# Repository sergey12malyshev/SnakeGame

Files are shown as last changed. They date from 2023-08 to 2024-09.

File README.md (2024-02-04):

# GameBox 
Game console project on STM32 controller and ILI9341 display. Contains two games: pac-man and arkanoid

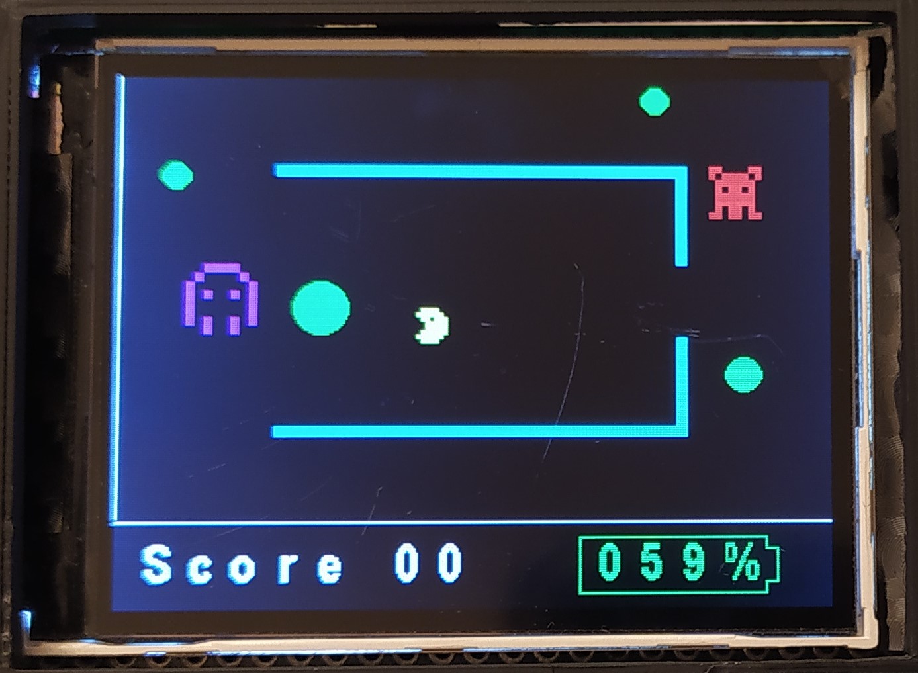
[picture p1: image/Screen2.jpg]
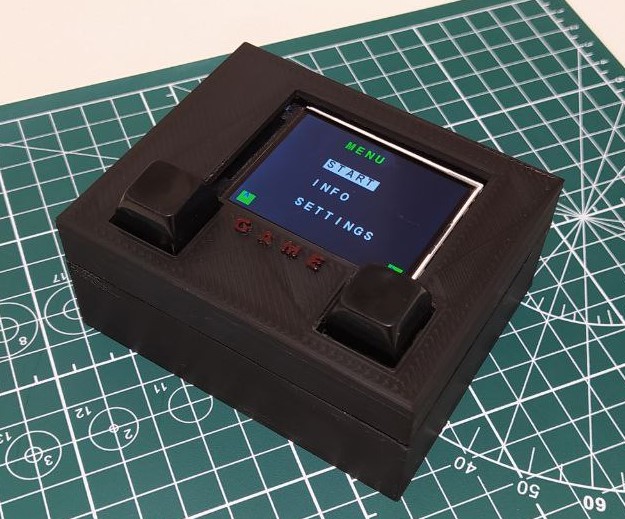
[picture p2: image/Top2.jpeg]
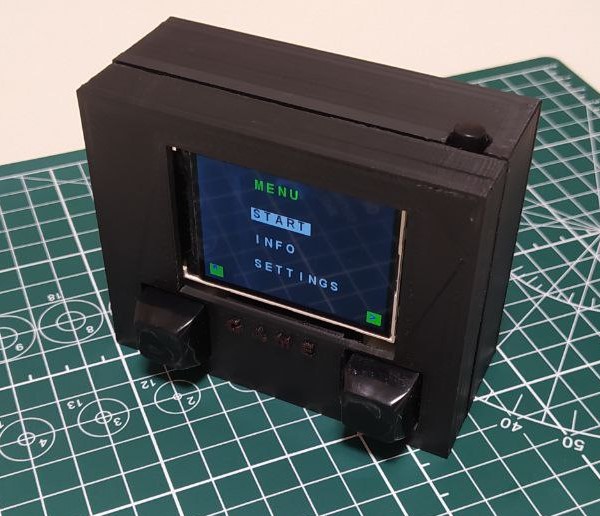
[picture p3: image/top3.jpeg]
  
 
## Tools

### Compiler
*GCC* (gcc-arm-none-eabi) version 5.4.1 20160919

### Setting up the build system in WINDOWS10 

1. Download GNU Arm Embedded Toolchain 
https://developer.arm.com/downloads/-/gnu-rm#:~:text=The%20GNU%20Arm%20Embedded%20Toolchain,Arm%20Cortex%2DR%20processor%20families
or
https://launchpad.net/gcc-arm-embedded/+download

2. Download Windows Build Tools binaries (Make, cp, rm, echo, sh...)
https://github.com/xpack-dev-tools/windows-build-tools-xpack/releases/

3. Add paths to the PATH environment variable in Windows

Подробная статья: https://habr.com/ru/articles/673522/

### RTOS
Prototreads AD v1.4

https://dunkels.com/adam/pt/

### Code editor
*VS Code* file Pac-ManGame.code-workspace

## Build 
To make the release project , run **makeProject.bat** (OR *make -j* cmd command)

To make the debug project , run **makeProjectDebug.bat** (OR *make -j1 debug* cmd command)

To clean the project, run **makeClean.bat** (OR *make clean*)

## Debugging
Open On-Chip Debugger (OCD) 0.10.0-00113-g0f83948 + GNU gdb (GNU Tools for ARM Embedded Processors) 7.10.1.20160923-cvs

Run **runOpenODC.bat** and run terminal: telnet localhost 4444

Run **runGDBserver.bat**

## Programm firmware
Connect ST-Link V2 to SWD connector. Run **programFlash.bat**

## Update firmware use system bootloader (DFU Mode)
Go to the device menu: MENU->UPDATE or CLI-> LOAD command to launch the system bootloader. Connect to PC via USB Type C. Run **updateFirmware.cmd** or launch STM32CubeProgrammer (select the desired COM-port and download the firmware).

## Command Line Interface

UART 115200 Baud rate

Connect: PA10 - RX / PA9 - TX

Terminal configuration file: utils\TERATERM.INI

Enter *help* command

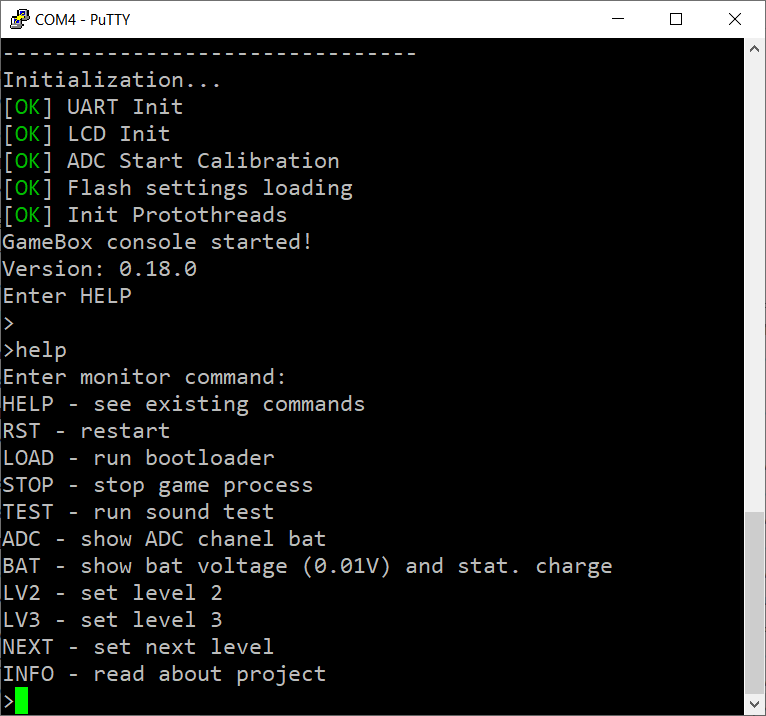
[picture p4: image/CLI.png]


### Static code analyzer
Cppcheck 2.10 https://cppcheck.sourceforge.io/

Run **RunStaticAnalysisCODE.cmd**

It is possible to output the analysis result to a file

### Unit tests
Simple unit tests are implemented in the file "unit_test.с". Unit tests are launched if the *RUN_UNIT_TEST* key is set or when building Debug

## Peripheral setup
STM32 CubeMX

(Checkboxes checked: *Enable Full Assert* и *Set All Free Pins as Analog*)

## Hardware
- Black pill STM32F103C8T6 (ARM Cortex-M3; 72 МГц; FLASH 64 кБ; ОЗУ 20 кБ)
- 2.8 TFT SPI 240x320 display (ILI9341)
- Buttons К1116КП2 (Hall effect sensor) or classic buttons
- TP4056 charge module with protection
- Battery 18650 li-ion
- CH340N USB-UART module
- Active buzzer
- Printed circuit board for soldering double-sided 7*9cm
- P-MOSFET
- USB-UART module (Optional for updating firmware via USB Type-C and working with CLI)
  
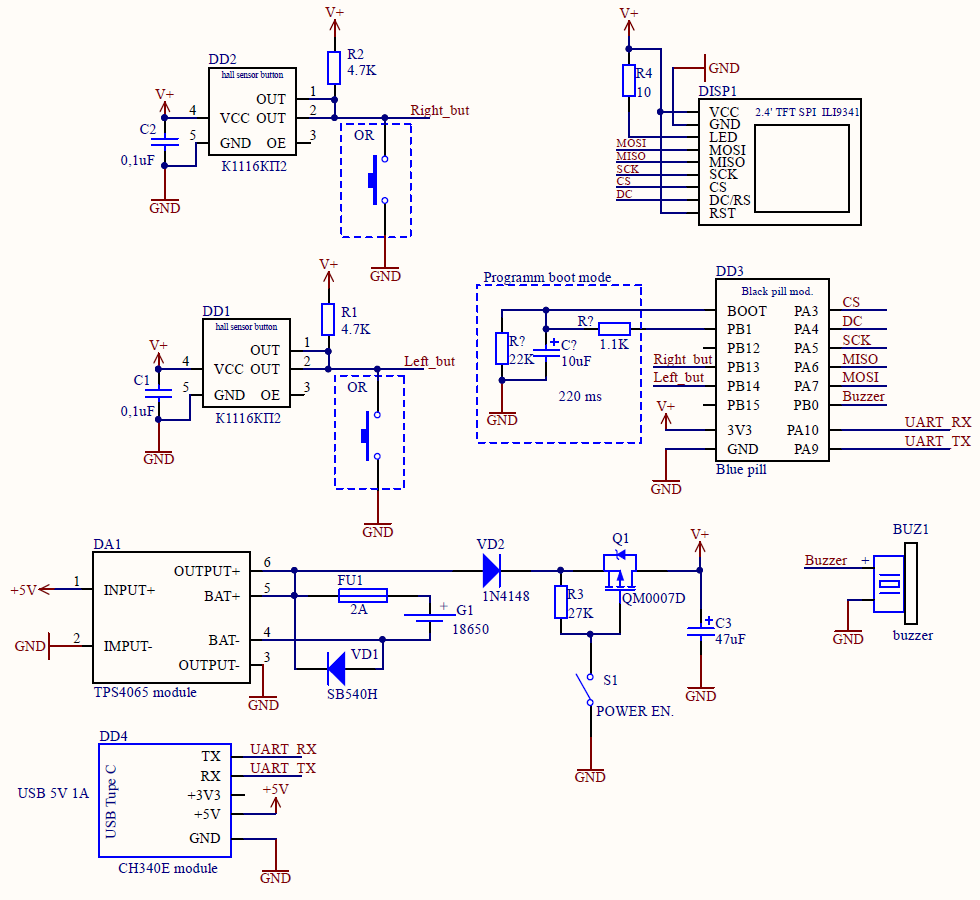
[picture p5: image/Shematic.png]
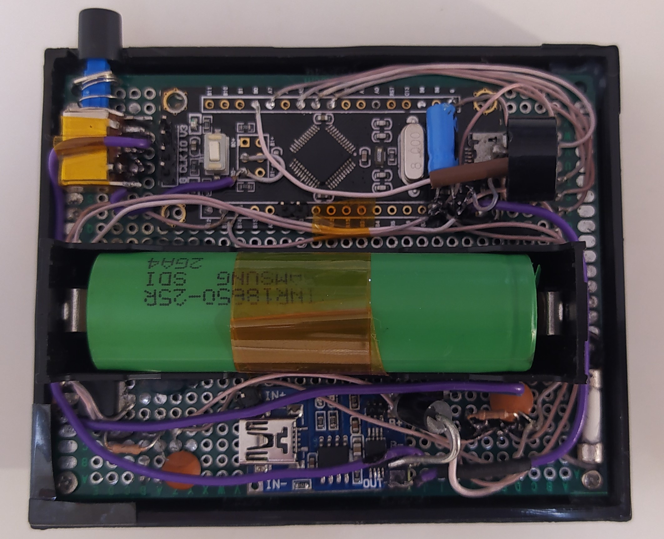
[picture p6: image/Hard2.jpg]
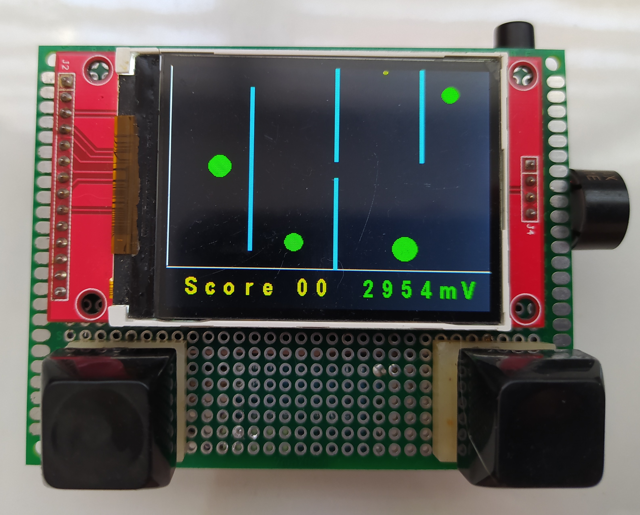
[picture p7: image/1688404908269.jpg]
   

*See Altium directory

*Be sure to check the BOOT0 output status on the debug board!*

## Case
Case models have been added to the project in the format **.stl**

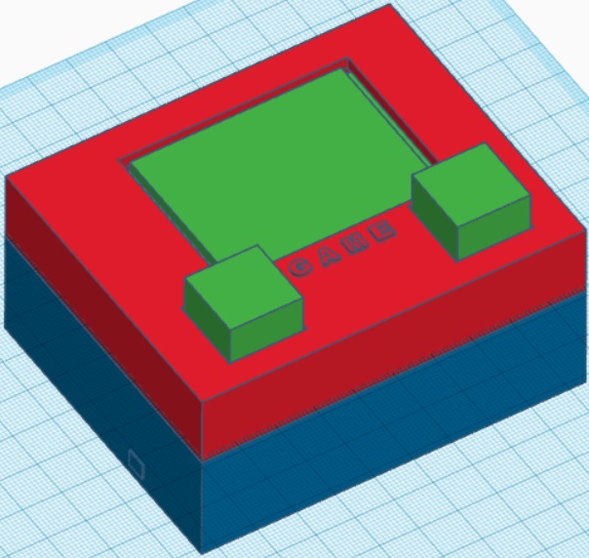
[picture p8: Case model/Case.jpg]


## gcc-arm-none-eabi

The magic name of the compiler gcc-arm-none-eabi means the following:

gcc - compiler name;

arm - processor architecture;

none - the compiler does not contribute any additional bootstrap code from itself;

eabi - code conforms to the EABI specification.

https://tuxotronic.org/post/arm-none-eabi/

## About repo

Work in the repository is carried out through the Git-flow branching model

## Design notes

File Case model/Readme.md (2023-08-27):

Корпус из двух половинок. Сделан в Tinkercad.com

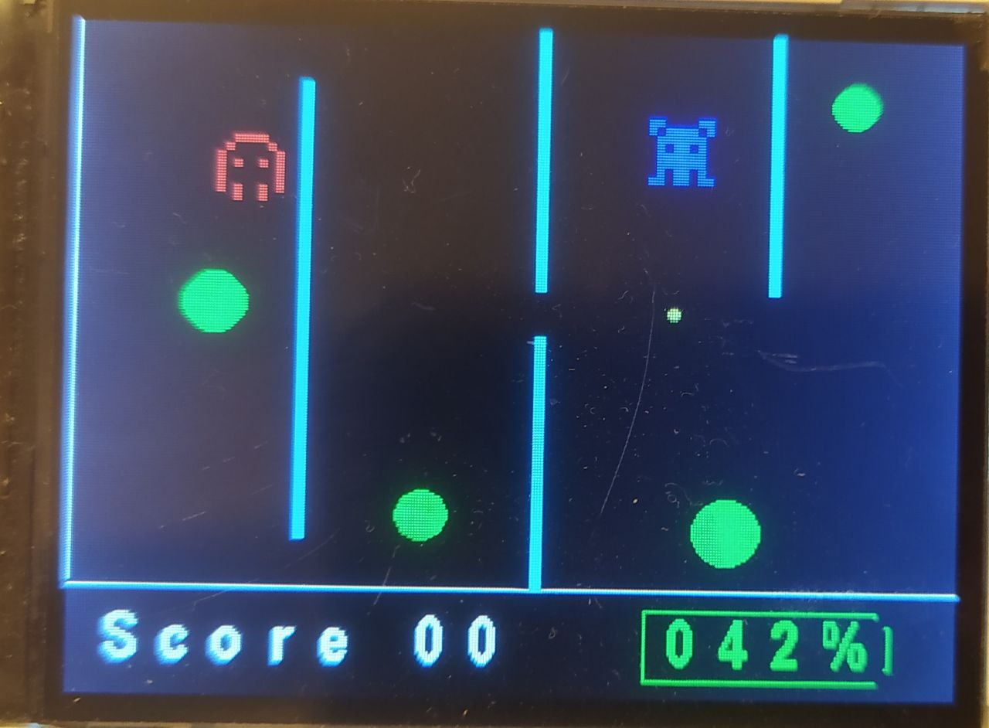
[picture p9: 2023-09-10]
image/b2e6b7b9-78c3-4203-983a-548b8aa62c95.jpg

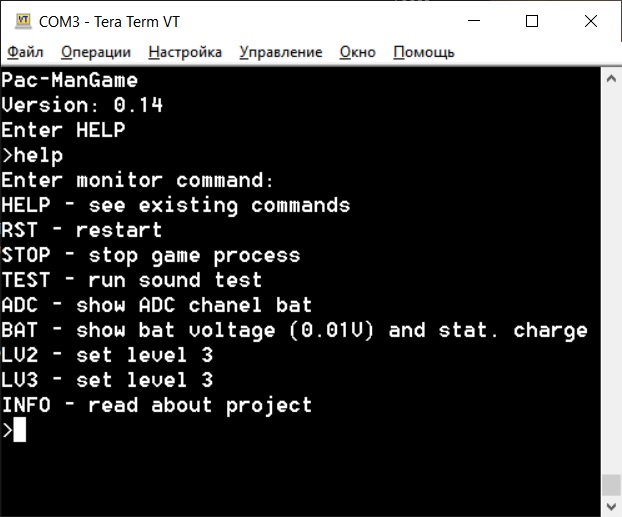
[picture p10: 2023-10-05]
image/ShellScreen.jpg

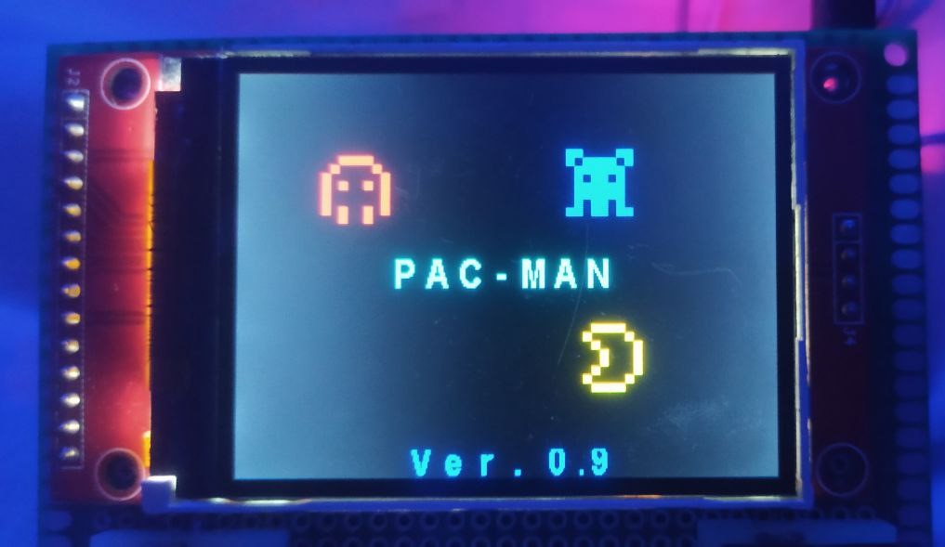
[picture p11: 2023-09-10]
image/db08b1eb-7112-4140-b000-8f4098d6f0e6.jpg

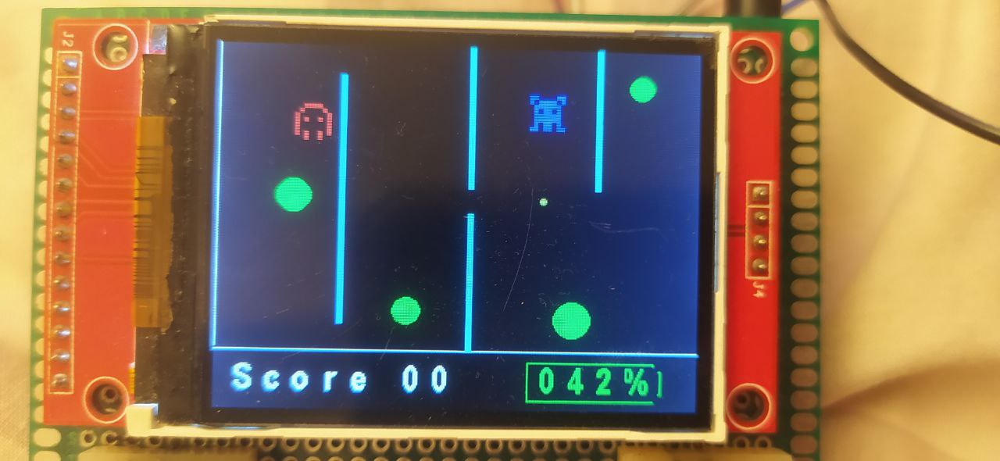
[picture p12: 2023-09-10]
image/7f3806c1-0cb3-4ed4-a501-857b09269990.jpg

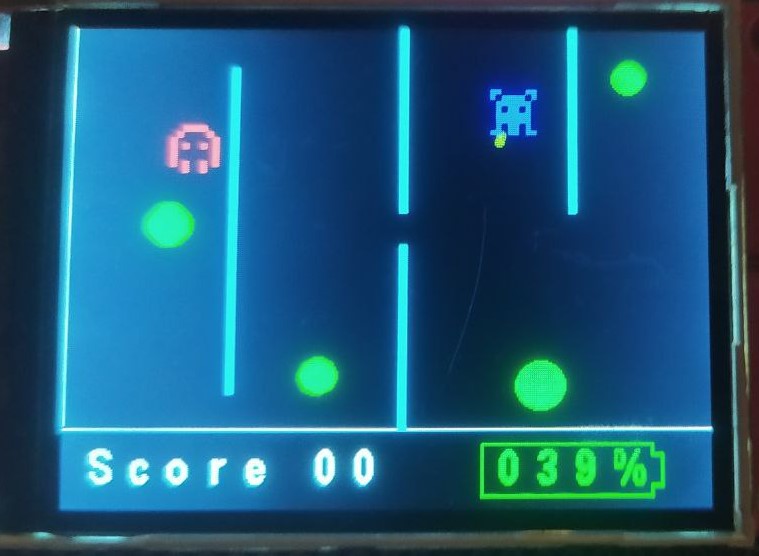
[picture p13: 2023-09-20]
image/b94825aa-9aec-4773-a235-eaeea46141b8.jpg

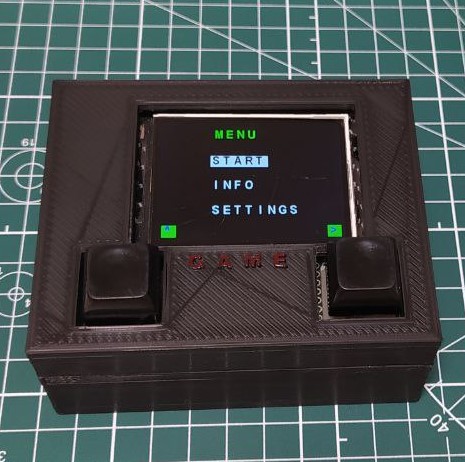
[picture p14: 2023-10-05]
image/Top.jpeg

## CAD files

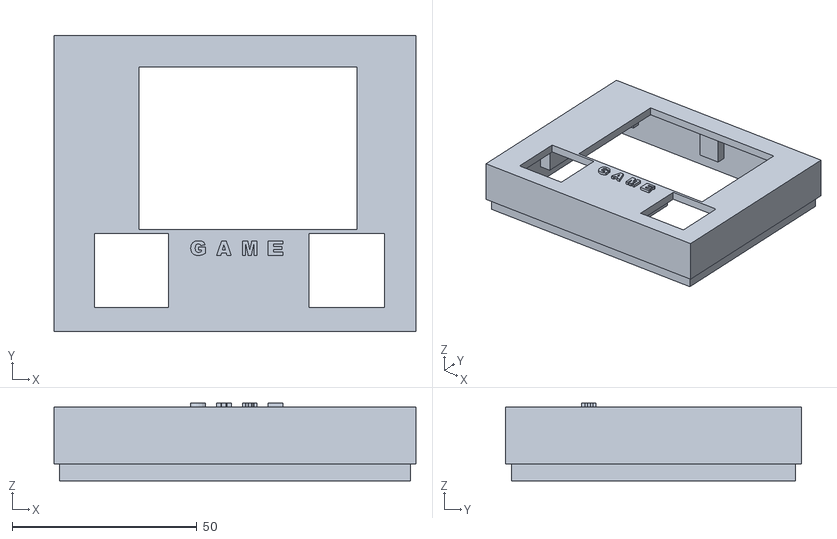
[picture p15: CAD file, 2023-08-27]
Case model/Корпус верхний.stl
98.0 x 80.0 x 21.0

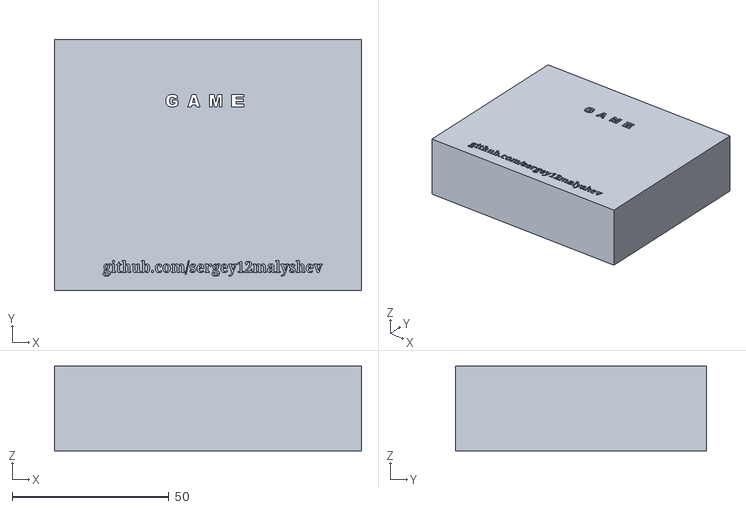
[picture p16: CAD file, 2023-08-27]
Case model/Корпус нижний.stl
98.0 x 80.0 x 27.0

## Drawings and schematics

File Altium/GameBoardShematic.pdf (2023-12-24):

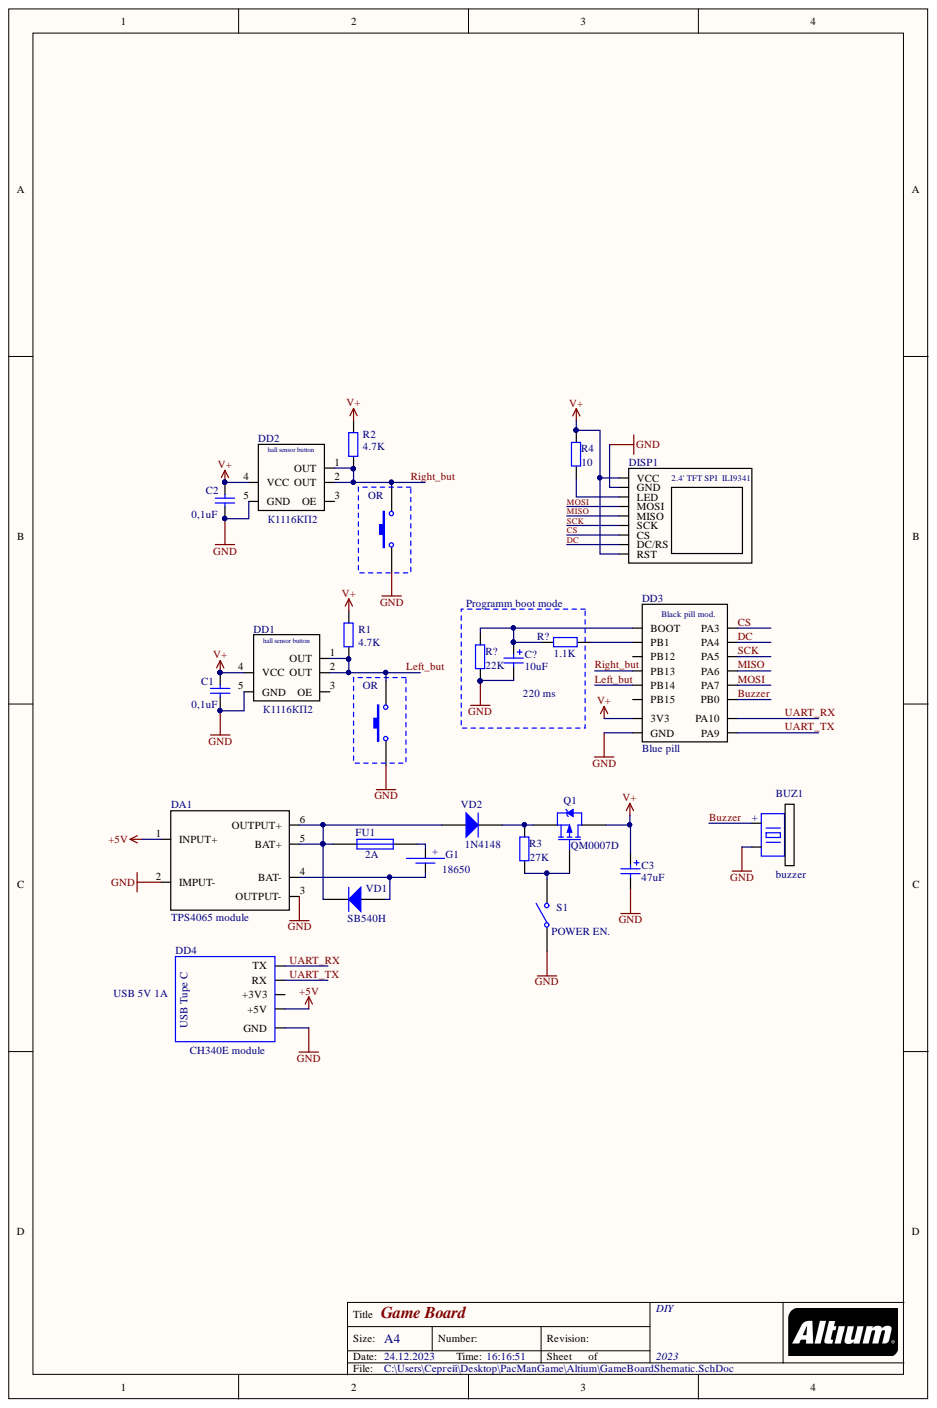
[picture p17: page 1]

Title Game Board | DIY 2023

Size: A4 | Number: | Revision:

Date: 24.12.2023 Time: 16:16:51 | | Sheet of
File: C:\Users\Сергей\Desktop\PacManGame\Altium\GameBoardShematic.SchDoc

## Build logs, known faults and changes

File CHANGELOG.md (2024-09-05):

# Version 0.20.0
Update time module
Adding GCC version check

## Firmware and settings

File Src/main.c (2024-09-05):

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
/* Includes ------------------------------------------------------------------*/
#include "main.h"

/* USER CODE BEGIN Includes */
#include <stdint.h>
#include <stdbool.h>
#include <stdio.h>
#include <string.h>
#include <stdlib.h>
#include <math.h>

#include "SPI_TFT.h"
#include "hard.h"
#include "Screens.h"
#include "Sound.h"
#include "filter.h"
#include "Menu.h"
#include "unit_test.h"
#include "workState.h"

#include "gameEngineThread.h"
#include "arkanoidEngineTread.h"
#include "batteryCheckThread.h"
#include "monitorThread.h"

#define LC_INCLUDE "lc-addrlabels.h"
#include "pt.h"
/* USER CODE END Includes */

/* USER CODE BEGIN PD */
#define GCC_VERSION ((__GNUC__ * 100) + (__GNUC_MINOR__ * 10) + ( __GNUC_PATCHLEVEL__ ))

#define STR_HELPER(x) #x
#define STR(x) STR_HELPER(x)

// Firmware builds require at least GCC 5.4.1
#if (GCC_VERSION < 541)
	#error "GCC compiler >= 5.4.1 required"
  #pragma message("GCC is " STR(__GNUC__)"."STR(__GNUC_MINOR__)"."STR(__GNUC_PATCHLEVEL__))
#endif
/* USER CODE END PD */

ADC_HandleTypeDef hadc1;

SPI_HandleTypeDef hspi1;
DMA_HandleTypeDef hdma_spi1_tx;

UART_HandleTypeDef huart1;

/* USER CODE BEGIN PV */
static struct pt gameEngine_pt;
static struct pt arkanoid_pt;
static struct pt batteryCheck_pt;
static struct pt monitorCheck_pt;

const int16_t SWversionMajor = 0;
const int16_t SWversionMinor = 20;
const int16_t SWversionPatch = 0;

const char HWversion[] = "1.0.0";

/* USER CODE END PV */

void SystemClock_Config(void);
static void MX_GPIO_Init(void);
static void MX_DMA_Init(void);
static void MX_ADC1_Init(void);
static void MX_SPI1_Init(void);
static void MX_USART1_UART_Init(void);
/* USER CODE BEGIN PFP */

/* USER CODE END PFP */

/* USER CODE BEGIN 0 */

void initProtothreads(void)
{
  PT_INIT(&gameEngine_pt);
  PT_INIT(&batteryCheck_pt);
  PT_INIT(&monitorCheck_pt);
}
/* USER CODE END 0 */

/**
  * @brief  The application entry point.
  * @retval int
  */
int main(void)
{
  /* MCU Configuration--------------------------------------------------------*/

  /* Reset of all peripherals, Initializes the Flash interface and the Systick. */
  HAL_Init();

  /* Configure the system clock */
  SystemClock_Config();

  /* Initialize all configured peripherals */
  MX_GPIO_Init();
  MX_DMA_Init();
  MX_ADC1_Init();
  MX_SPI1_Init();
  MX_USART1_UART_Init();
  /* USER CODE BEGIN 2 */
  sendUART("--------------------------------\r\n");
  sendUART("Initialization...\r\n");
  heartBeatLedEnable();
  UART_receve_IT();
  sendUART(OK_G "UART Init\r\n");
  HAL_Delay(250); // Добавим задержку, для исключения дребезга питания
  LCD_Init();
  LCD_setOrientation(ORIENTATION_LANDSCAPE_MIRROR);
  sendUART(OK_G "LCD Init\r\n");
  screenBootProcess();
  HAL_Delay(1500); 
  screenSaver();
  resetTest();
  HAL_Delay(150);
  soundPowerOn();

  HAL_ADCEx_Calibration_Start(&hadc1);
  HAL_ADC_Start_IT(&hadc1);
  sendUART(OK_G "ADC Start Calibration\r\n");
  
  #if RUN_UNIT_TEST
  runUnitTests();
  #endif

  HAL_Delay(900);
  setDefaultValueFilter(3200U);

  uint32_t speedIsFlash = flash_read(flash_get_page());
  if (speedIsFlash < 55U)
  {
    setSpeedGame(speedIsFlash);
    sendUART(OK_G "Flash settings loading\r\n");
  }
  screenMainMenu();

  initProtothreads();
  sendUART(OK_G "Init Protothreads\r\n");
  sendUART_hello();
  /* USER CODE END 2 */

  /* Infinite loop */
  /* USER CODE BEGIN WHILE */
  while (1)
  { 
    BatteryCheckThread(&batteryCheck_pt);
    MonitorTread(&monitorCheck_pt);

    switch (getWorkState())
    {
      case MENU:
        mainMenu();
        break;
      case GAME1:
        GameEngineThread(&gameEngine_pt);
        break;
      case GAME2:
        ArcanoidGameEngineThread(&arkanoid_pt);
        break;
    
      default:
        assert_param(0); // Error
        break;
    }
    /* USER CODE END WHILE */

    /* USER CODE BEGIN 3 */
  }
  /* USER CODE END 3 */
}

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


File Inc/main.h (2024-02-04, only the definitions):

#define DC_Pin GPIO_PIN_3
#define DC_GPIO_Port GPIOA
#define CS_Pin GPIO_PIN_4
#define CS_GPIO_Port GPIOA
#define BOOT_EN_Pin GPIO_PIN_1
#define BOOT_EN_GPIO_Port GPIOB
#define LED_Pin GPIO_PIN_12
#define LED_GPIO_Port GPIOB
#define WDT_CLEAR   __NOP() // заготовка под wdt
#define OK_G "[\033[32mOK\033[0m] "

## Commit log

2023-06-20 Первая фиксация demo
2023-06-20 Добавление реакции на касание еды. Добавление функционала
2023-06-21 Добавление второй кнопки
2023-06-22 Устранение проблемы с положениями
2023-06-22 Сделана реакция на касание стены
2023-06-22 Первая рабочая версия
2023-06-22 Промежуточная фиксация
2023-06-22 Фиксация
2023-06-22 Разные размеры еды
2023-06-23 Перенёс файл дисплея
2023-06-23 Отформатировал библиотеку
2023-06-23 Добавление функционала по контролю за питанием
2023-06-23 Доработка функционала
2023-06-23 Пересборка проекта с новой версией пакетов cubeMX
2023-06-24 Выделение железной логики в отдельный файл
2023-06-24 Вынесение железной логики в отдельеые файлы. Добавил версию
2023-06-25 Добавление функции звука
2023-06-25 Настройка порта под звук
2023-06-25 Поправил размеры поля
2023-06-25 Изменение распиновки
2023-06-25 Добавление функционала
2023-06-26 Увеличил размер змейки
2023-06-27 Перевод проекта на компилятор gcc систему сборки Make
2023-06-27 Уменьшение количества генерируемых CubMX-ом файлов
2023-06-27 Добавление скриптов автоматизированной сборки
2023-06-27 Дополнение README.md
2023-06-27 Добавление скрипта статического анализа кода
2023-06-27 Все свободные пины в аналоговый режим и включаем полный контроль ошибок
2023-06-28 Правка README.md
2023-06-28 Добавил даташиты
2023-06-29 Реализация уровней
2023-06-29 Реализация второго уровня
2023-06-30 Выделение логики levelUp
2023-06-30 Усложнение уровня
2023-06-30 Забыл убрать заглушку
2023-07-03 Добавление фото
2023-07-04 Выводим процент заряда
2023-07-05 Доработка алгоритма определения напряжения АКБ
2023-07-05 Добавление графика расчета SOC
    [SOC_vs_Voltage.xlsx]
2023-07-06 Добавление контура батареи. Перекодировка в UTF8
2023-07-06 Доработка символа АКБ
2023-07-06 дизигн
2023-07-06 Создание третьего уровня
2023-08-02 Добавил комментарий
2023-08-02 Обновление номера версии
2023-08-05 Увеличил предел по напряжению
2023-08-19 Множество изменений: - добавление протопотоков - разделение кода на файлы - выводим размер прошивки при сборке
2023-08-19 Реализация протопотоков
2023-08-20 Рефакторинг
2023-08-20 Устранение ошибки
2023-08-20 Выделение API работы со звуком в отдельный файл
2023-08-20 Реализация изображений
2023-08-20 Переименование игры в Pac-Men
2023-08-20 Добавление файла для ручной конвертации изображений
    [ImageDecode.xlsx]
2023-08-20 Доработка дизайна заставки
2023-08-21 Добавление монстров в игровой процесс
2023-08-21 Оптимизация
2023-08-21 Изменил расположение монстров
2023-08-22 Добавление проверки на попадание в монстров Добавил атрибут для отключения предупреждения
2023-08-23 Доработка монстров
2023-08-23 -Забыл добавить исходники звука - Переименование проекта
2023-08-25 Реализация меню
2023-08-25 Оптимизация драйвера кнопок
2023-08-26 Уменьшил кучу, увеличил стэк Переименовал файл настройки пректа
2023-08-26 Изменение дизайна и имени прошивки
2023-08-27 Проведен рефакторинг кода: выделение цветов в отдельный файл
2023-08-27 Добавление моделей корпуса
    [Корпус верхний.stl, Корпус нижний.stl]
2023-08-27 Меняем цвет монстров
2023-08-30 Добавление информации о времени сборки
2023-08-30 Добавил коммент
2023-09-06 Объявляем локально внешние переменные
2023-09-10 Добавление терминала (CLI)
2023-09-10 add jpg case
2023-09-17 Условная компиляция монитора
2023-09-18 Обновление README.md
2023-09-20 1. Add monitor command 2. Eliminating the gaming process error
    [monitorThread.c]
2023-09-20 Добавляем настройку портов
2023-09-20 Add Altium project
    [GameBoardShematic.SchDoc, Schlib1.SchLib]
2023-09-20 Переделка процесса работы с АКБ
2023-09-22 1. Cчетчик очков растёт до проигрыща 2. рефакторинг
2023-09-23 Добавил фильтр на напряжение АКБ
2023-09-23 Добавляем PDF на кнопку
2023-09-23 update model
    [ImageDecode.xlsx]
2023-09-25 устранение ошибки с неверным положением
2023-09-25 Shematic update
    [GameBoardShematic.SchDoc, Schlib1.SchLib]
2023-10-05 Add image case
2023-10-07 Add check assert failed
    [main.c]
2023-10-07 Работаем с ADC через прерывания. Увеличиваем время сэмплирования
2023-10-19 1. Добавляем предустановку фильтра 2. Подготовил макрос под WDT 3. Пищим бипером при аварии АКБ 4. Выходим по кнопке из STOP-теста
2023-11-12 Create utills directory. Add Teraterm config file
    [ImageDecode.xlsx]
2023-12-13 Add CMSIS driver Flash
2023-12-24 Добавление возможности программирования через системный загрузчик переходя из целевой программы
2023-12-24 Update Altium project
    [GameBoardShematic.SchDoc, Schlib1.SchLib]
2024-01-03 Добавление проверки при дебаге на неверные зеачения switch-case
2024-01-04 Забыл закоммитить файлы
2024-01-04 Доработка меню и графики
2024-01-04 Макрос USE_FULL_ASSER устанавливаем в debug сборке
2024-03-14 Add all drivers

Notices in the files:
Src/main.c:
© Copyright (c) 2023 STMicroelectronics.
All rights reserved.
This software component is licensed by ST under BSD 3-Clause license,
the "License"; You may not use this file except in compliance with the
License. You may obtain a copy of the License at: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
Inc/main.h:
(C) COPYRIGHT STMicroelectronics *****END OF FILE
